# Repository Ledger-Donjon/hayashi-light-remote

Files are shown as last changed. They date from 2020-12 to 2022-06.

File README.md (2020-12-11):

# Hayashi-light-remote

An Open-Source and Open-Hardware USB dongle for controlling Hayashi light source
LA-150CE remotely. It should also be compatible with LA-150UE, LA-100IR and
LA-150FBU, but this has not been tested (any feedback is welcome).

The halogen lamp can be turned on and off, and its intensity can be adjusted
from the software.

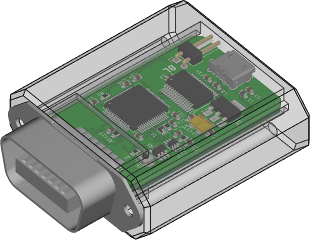
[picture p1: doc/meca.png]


# Python API

Once the dongle is connected to the lamp and the computer, the provided Python3
library can be used to communicate with the dongle and take control of the lamp:

```python
import hyshlr

device = hyshlr.HyshLR()
device.lamp = True
device.intensity = 0.5
```

# External documentation

[Manufacturer documentation with remote connector interface specification](http://www.korin-hayashi.com.cn/uploadfile/2018/1030/20181030095820716.pdf)

## Licensing

This project is licensed under the GNU Lesser General Public Licence version 3
(LGPLv3). See COPYING and COPYING.LESSER for license details.

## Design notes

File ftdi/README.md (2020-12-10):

# FTDI EEPROM programming

Disconnect all USB-to-serial devices but the Hayashi remote dongle.

Install the package `ftdi_eeprom` and execute the `flash.sh` script as root to
program the EEPROM memory of the dongle FT232H device. This will configure the
vendor and description strings to respectively "Ledger" and
"hayashi-light-remote".

Configuring the EEPROM is optional, but when programmed, the software is able
to recognize automatically which serial port corresponds to the dongle.

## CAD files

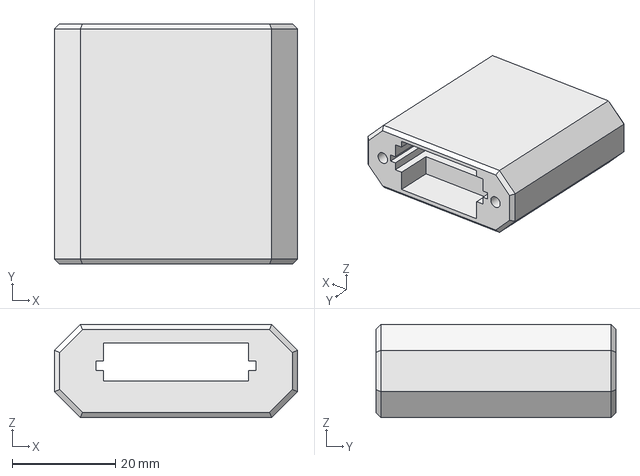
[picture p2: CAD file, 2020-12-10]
meca/enclosure.step
47.0 x 46.5 x 18.0 mm

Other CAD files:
meca/enclosure.FCStd

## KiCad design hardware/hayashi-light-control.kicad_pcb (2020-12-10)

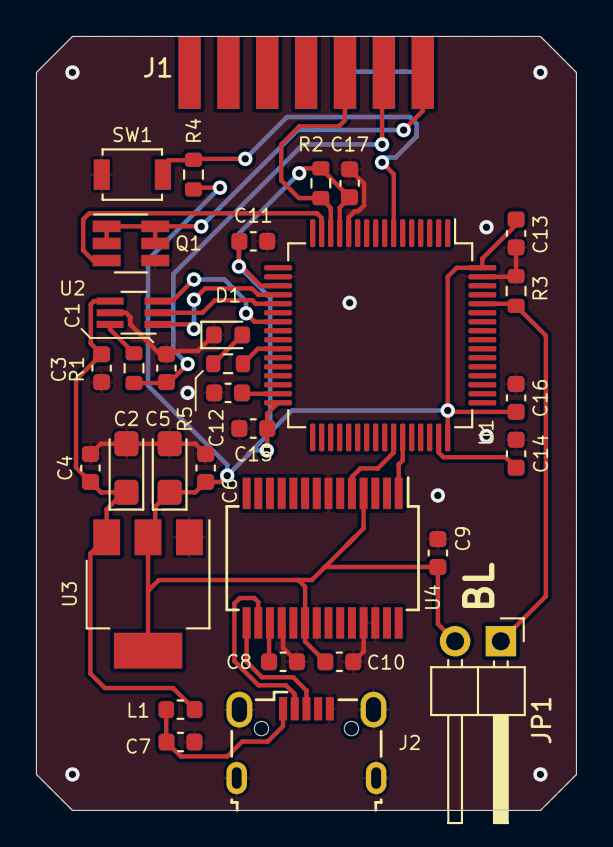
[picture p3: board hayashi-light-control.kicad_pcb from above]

Board: 2 copper layers, 30.0 x 43.0 mm, 34 parts (1 on the bottom side), 23 nets.

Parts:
C1, C12, C14: 2.2µ; C_0603_1608Metric
C2, C5: 10µ; CP_EIA-3216-10_Kemet-I
C3, C4, C6, C7, C8, C9, C10, C11, C13, C15, C16, C17: 100n; C_0603_1608Metric
D1: Green; D_0603_1608Metric
J1: Conn_02x07_Top_Bottom; Amphenol_5710140
J2: USB_B_Micro; USB_Micro-B_Wuerth_629105150521
JP1: Jumper_2_Open; PinHeader_1x02_P2.54mm_Horizontal
L1: Ferrite_Bead_Small; L_0603_1608Metric
LOGO1: DONJON LOGO; donjon-2000
Q1: STT6N3LLH6; SOT-23-6_Handsoldering
R1: R_Small; R_0603_1608Metric
R2: 10K; R_0603_1608Metric
R3, R4: 10k; R_0603_1608Metric
R5: 330; R_0603_1608Metric
SW1: RESET; SW_SPST_B3U-1000P
U1: STM32F205RET6; LQFP-64_10x10mm_P0.5mm
U2: AD5621B; SOT-363_SC-70-6_Handsoldering
U3: LD1117S33TR_SOT223; SOT-223-3_TabPin2
U4: FT232RL; SSOP-28_5.3x10.2mm_P0.65mm

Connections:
+3V3: C5.1, C6.1, C9.2, C10.2, C11.1, C13.1, C15.1, C16.1, C17.1, JP1.2 (B), R2.1, R4.1, U1.13 (VDDA), U1.19 (VDD), U1.32 (VDD), U1.48 (VDD), U1.64 (VDD), U3.2 (VO), U4.4 (VCCIO), U4.20 (VCC)
/CON1: J1.1, Q1.1, Q1.2, Q1.5, Q1.6
/CON2: C1.1, J1.2, R1.1
/CON3: J1.3, R2.2, U1.14 (PA0)
/LAMP_ON_OFF: Q1.3, U1.15 (PA1)
/SPI_MOSI: U1.23 (PA7), U2.3 (SDIN)
/SPI_NSS: U1.20 (PA4), U2.1 (~SYNC)
/SPI_SCK: U1.21 (PA5), U2.2 (SCLK)
/TX: U1.43 (PA10), U4.1 (TXD)
/TX_1: U1.42 (PA9), U4.5 (RXD)
GND: C1.2, C2.2, C3.2, C4.2, C5.2, C6.2, C7.1, C8.2, C9.1, C10.1, C11.2, C12.2, C13.2, C14.2, C15.2, C16.2, C17.2, D1.1 (K), J1.8, J1.9, J1.10, J2.5 (GND), J2.6 (Shield), Q1.4, R3.2, SW1.1, U1.12 (VSSA), U1.18 (VSS), U1.63 (VSS), U2.5 (GND), U3.1 (GND), U4.7 (GND), U4.18 (GND), U4.21 (GND), U4.25 (AGND), U4.26 (TEST)
unnamed: C7.2, J2.1 (VBUS), L1.1
unnamed: C8.1, U4.17 (3V3OUT)
unnamed: C12.1, U1.31 (VCAP_1)
unnamed: C14.1, U1.47 (VCAP_2)
unnamed: D1.2 (A), R5.2
unnamed: J2.2 (D-), U4.16 (USBD-)
unnamed: J2.3 (D+), U4.15 (USBD+)
unnamed: JP1.1 (A), R3.1, U1.60 (BOOT0)
unnamed: R1.2, U2.6 (VOUT)
unnamed: R4.2, SW1.2, U1.7 (NRST)
unnamed: R5.1, U1.26 (PB0)
VBUS: C2.1, C3.1, C4.1, L1.2, U2.4 (VDD), U3.3 (VI)

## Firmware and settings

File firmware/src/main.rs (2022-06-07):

// This file is part of hayashi-light-remote
//
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
//
// Copyright 2020 Ledger SAS, written by Olivier Hériveaux

#![no_std]
#![no_main]

use core::panic::PanicInfo;
use stm32f2::stm32f215;

static mut USART1_QUEUE: heapless::spsc::Queue<u8, heapless::consts::U128> =
    heapless::spsc::Queue(heapless::i::Queue::new());

#[panic_handler]
fn panic(_: &PanicInfo) -> ! {
    unsafe {
        // In case of panic, the peripherals may have already been taken, and we
        // cannot take it again... But this is panic, we can do dirty things and
        // call steal to use peripherals anyway!
        // Here we just blink the red LED forever to indicate there is a
        // problem.
        let peripherals = stm32f215::Peripherals::steal();
        set_led(&peripherals, false);
        loop {
            for _ in 0..50000 {
                set_led(&peripherals, true);
            }
            for _ in 0..50000 {
                set_led(&peripherals, false);
            }
        }
    }
}

pub extern "C" fn handler_default() { loop {}; }

/// USART interrupt handler. Called in case of data byte reception or overrun.
/// When a byte is received, it is pushed in the USART queue. If the queue is
/// full, the program will panic.
pub extern "C" fn handler_usart1() {
    unsafe {
        let mut producer = USART1_QUEUE.split().0;
        let peripherals = stm32f215::Peripherals::steal();
        if peripherals.USART1.sr.read().rxne().bit() {
            // If queue is full, panic!
            producer.enqueue(peripherals.USART1.dr.read().bits() as u8).unwrap();
        } else {
            // This is probably an overrun error.
            panic!();
        }
    }
}

#[link_section=".isr_vectors.reset"]
#[no_mangle]
pub static reset_vector: unsafe extern "C" fn() -> ! = _start;

#[link_section=".isr_vectors"]
#[no_mangle]
pub static interrupt_vectors: [unsafe extern "C" fn(); 95] = {
    let mut v: [unsafe extern "C" fn(); 95] = [handler_default; 95];
    v[51] = handler_usart1;
    v
};

/// Toggle the LED on or off.
///
/// # Arguments
///
/// * `peripherals` - This method needs to borrow the peripherals.
/// * `state` - true to turn on the LED, false to turn off.
fn set_led(peripherals: &stm32f215::Peripherals, state: bool) {
    peripherals.GPIOB.odr.modify(|_, w| { w.odr0().bit(state) });
}

/// Toggle the lamp on or off.
///
/// # Arguments
///
/// * `peripherals` - This method needs to borrow the peripherals.
/// * `state` - true to turn on the lamp, false to turn off.
fn set_lamp(peripherals: &stm32f215::Peripherals, state: bool) {
    peripherals.GPIOA.odr.modify(|_, w| { w.odr1().bit(!state) });
}

/// Return true if lamp is dead
fn lamp_burnout(peripherals: &stm32f215::Peripherals) -> bool {
    !peripherals.GPIOA.idr.read().idr0().bit()
}

/// Approximated delay function. Precise enought for what we need to do...
#[inline(never)]
fn delay_ms(duration: u32) {
    // Estimated duration for each loop: 7 clock cycles.
    assert!(duration <= 0xffffffff / 64000);
    let count: u32 = (duration * 64000) / 7;
    for _ in 0..count {
        cortex_m::asm::nop();
    }
}

/// Receives a byte from USART1. Blocks until data is available.
fn usart1_rx() -> u8 {
    unsafe {
        let mut producer = USART1_QUEUE.split().1;
        loop {
            if let Some(byte) = producer.dequeue() { return byte; }
        }
    }
}

/// Receive a 16-bits unsigned int from USART1. Blocks until all data is
/// available.
fn usart1_rx_u16() -> u16 {
    let h = usart1_rx();
    let l = usart1_rx();
    ((h as u16) << 8) + (l as u16)
}

/// Transmit a byte over USART1.
///
/// # Arguments
///
/// * `peripherals` - This method needs to borrow the peripherals.
/// * `value` - Byte to be transmitted.
fn usart1_tx(peripherals: &stm32f215::Peripherals, value: u8) {
    peripherals.USART1.dr.write(|w| { w.dr().bits(value as u16) });
    // Wait until byte is transferred into the shift-register.
    while !peripherals.USART1.sr.read().txe().bit() {};
}

/// Transmit a string over USART1.
///
/// # Arguments
///
/// * `peripherals` - This method needs to borrow the peripherals.
/// * `s` - String
fn usart1_tx_str(peripherals: &stm32f215::Peripherals, s: &str) {
    for c in s.bytes() {
        usart1_tx(&peripherals, c);
    }
}

/// Transmit 16 bits over SPI1
///
/// # Arguments
///
/// * `peripherals` - This method needs to borrow the peripherals.
/// * `value` - Value to be transmitted.
fn spi1_tx_u16(peripherals: &stm32f215::Peripherals, value: u16) {
    while !peripherals.SPI1.sr.read().txe().bit() {};
    peripherals.GPIOA.odr.modify(|_, w| { w.odr4().clear_bit() });
    peripherals.SPI1.dr.write(|w| { w.dr().bits(value) });
    while !peripherals.SPI1.sr.read().rxne().bit() {};
    peripherals.GPIOA.odr.modify(|_, w| { w.odr4().set_bit() });
    peripherals.SPI1.dr.read();
}

/// Configure internal Flash memory interface.
/// This changes the Flash latency to be compatible with PLL settings.
fn setup_flash(peripherals: &stm32f215::Peripherals){
    unsafe {
        peripherals.FLASH.acr.modify(|_, w| { w.latency().bits(2) });
    }
}

/// Configure PLL
fn setup_pll(peripherals: &stm32f215::Peripherals){
    let rcc = &peripherals.RCC;
    // Disable PLL
    rcc.cr.modify(|_, w| { w.pllon().clear_bit() });
    // HSI = 16 MHz
    // F = ((HSI (N / M) / P
    // Constraints to be respected:
    // 50 <= N <= 432
    // 2 <= M <= 63
    // Here the target frequency is 64 MHz
    unsafe {
        rcc.pllcfgr.modify(|_, w|
            { w.plln().bits(64).pllm().bits(8).pllp().div2() });
    }
    // Enable PLL and wait it to be locked.
    rcc.cr.modify(|_, w| { w.pllon().set_bit() });
    while !rcc.cr.read().pllrdy().bit() {}
    // Switch to PLL clock
    rcc.cfgr.modify(|_, w| { w.sw().pll() });
}

#[no_mangle]
pub extern "C" fn _start() -> ! {
    // Get .bss segment position for .bss initialization performed in _start.
    extern {
        static _bss: u32;
        static _ebss: u32;
    }
    // Clear RAM of .bss section before doing anything!
    unsafe {
        for i in ((&_bss as *const u32) as u32 .. (&_ebss as *const u32) as u32)
            .step_by(4) {
            core::ptr::write_volatile(i as *mut u32, 0u32);
        }
    }

    let peripherals = stm32f215::Peripherals::take().unwrap();
    setup_flash(&peripherals);
    setup_pll(&peripherals);

    peripherals.RCC.apb2enr.write(|w| {
        w.usart1en().set_bit()
        .spi1en().set_bit()
    });
    // PA0: LAMP_BURNOUT
    // PA1: LAMP_ON_OFF
    // PA4: SPI_NSS
    // PA5: SPI_SCK
    // PA6: SPI_MISO (not connected)
    // PA7: SPI_MOSI
    // PA9: USART1 TX
    // PA10: USART1 RX
    // PB0: LED
    // Enable clock for PORT A, and PORT B peripherals.
    peripherals.RCC.ahb1enr.write(
        |w| { w.gpioaen().set_bit().gpioben().set_bit() } );
    let gpioa = &peripherals.GPIOA;
    gpioa.moder.write(|w| {
        w.moder1().output()
        .moder4().output()
        .moder5().alternate()
        .moder7().alternate()
        .moder9().alternate()
        .moder10().alternate()
    });
    gpioa.ospeedr.write(|w| {
        w.ospeedr10().very_high_speed()
        .ospeedr9().very_high_speed()
        .ospeedr4().very_high_speed()
        .ospeedr5().very_high_speed()
        .ospeedr7().very_high_speed()
    });
    gpioa.odr.modify(|_, w| { w.odr4().set_bit() }); // SPI_NSS high by default
    gpioa.afrl.write(|w| { w.afrl5().af5().afrl7().af5() });
    gpioa.afrh.write(|w| { w.afrh9().af7().afrh10().af7() });
    peripherals.GPIOB.moder.modify(|_, w| { w.moder0().output() });

    // Configure UART1
    // UART Enable, Transmitter Enable, Receiver Enable
    peripherals.USART1.cr1.write(
        |w| { w.ue().set_bit().te().set_bit().re().set_bit() });
    peripherals.USART1.cr2.write(|w|{ w.stop().bits(2) });
    // Baudrate is Fck/(8*(2-OVER8)*DIV)
    // Fck = 64 MHz
    // OVER8 = 0
    // DIV = BRR / 16
    // Here we set 9600 bps
    let brr_value = 6666;
    peripherals.USART1.brr.write(
        |w| { w.div_mantissa().bits(brr_value >> 4)
        .div_fraction().bits((brr_value & 0x0f) as u8) });
    // Enable interrupt for USART1
    peripherals.USART1.cr1.modify(|_, w| { w.rxneie().set_bit() });
    unsafe {
        cortex_m::peripheral::NVIC::unmask(stm32f215::Interrupt::USART1);
    }

    // Configure SPI1
    let spi1 = &peripherals.SPI1;
    spi1.cr1.write(|w| {
        w.spe().set_bit()
        .ssi().set_bit()
        .ssm().set_bit()
        .br().bits(7)
        .mstr().set_bit()
        .dff().set_bit()
        .cpha().set_bit() });

    let mut lamp_state = false;
    let mut lamp_intensity = 0u16;
    set_led(&peripherals, lamp_state);
    set_lamp(&peripherals, lamp_state);
    spi1_tx_u16(&peripherals, lamp_intensity);
    // Give some time for the FT232 to boot-up.
    delay_ms(500);

    loop
    {
        let command_byte = usart1_rx();
        match command_byte {
            // Get version string
            0x01 => {
                usart1_tx_str(&peripherals, "hyshlc-v1.0");
                usart1_tx(&peripherals, 0);
            }
            // Switch light On/Off
            0x02 => {
                lamp_state = usart1_rx() != 0;
                set_lamp(&peripherals, lamp_state);
                set_led(&peripherals, lamp_state);
                usart1_tx(&peripherals, command_byte);
            }
            // Set light power (control the DAC)
            0x03 => {
                lamp_intensity = usart1_rx_u16();
                spi1_tx_u16(&peripherals, lamp_intensity);
                usart1_tx(&peripherals, command_byte);
            }
            // Get lamp state
            0x04 => {
                usart1_tx(&peripherals, command_byte);
                usart1_tx(&peripherals, lamp_state as u8);
            }
            // Get lamp intensity
            0x05 => {
                usart1_tx(&peripherals, command_byte);
                usart1_tx(&peripherals, (lamp_intensity >> 8) as u8);
                usart1_tx(&peripherals, (lamp_intensity & 0xff) as u8);
            }
            // Get lamp burnout indication
            0x06 => {
                usart1_tx(&peripherals, command_byte);
                usart1_tx(&peripherals, if lamp_burnout(&peripherals) { 1 } else { 0 });
            }
            _ => {
                // Unknown command. Panic!
                panic!();
            }
        }
    }
}

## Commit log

2020-12-10 Initial release
    [enclosure.FCStd, enclosure.step, ft232.kicad_sch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]
2020-12-11 Renammed property power to intensity
2020-12-11 Added current setting readout
2020-12-11 Removed debug print

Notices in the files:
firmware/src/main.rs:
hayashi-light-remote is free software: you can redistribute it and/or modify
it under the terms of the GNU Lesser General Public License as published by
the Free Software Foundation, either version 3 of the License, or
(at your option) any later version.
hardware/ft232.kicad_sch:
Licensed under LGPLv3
